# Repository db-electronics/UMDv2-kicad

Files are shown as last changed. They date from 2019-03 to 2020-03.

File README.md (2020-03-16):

# UMDv2
The Universal Mega Dumper v2 project aims to be a complete open-sourced solution for cartridge dumping and writing. It includes a very performant MCU which has a direct memory connection to a generalized databus consisting of 24 address bits and 16 data lines. Along with a dozen or so control signals, it should be sufficient to interface with most cartridge types.

## Cartridge Adapters
The UMDv2 by itself only includes a generalized connector with all its interfacing signals. Cartridge adapters must be used in order to interface to the physical media. All cartridge adapters, as they are created, are added to this project as submodules and will be linked in the CartAdapters directory.

### Cartridge Adapter ID
Each cartridge adapter has an MCP23008 on the I2C bus which identifies the console type for the adapter and thus prevents contention on IO.

* 0x00: no adapter
* 0x01: Sega Genesis 
* 0x02: Sega Master System

# Dependencies
## Parts Libraries
All components in this project depend on my KiCad libraries which are available at https://github.com/db-electronics/kicadlib . I don't use any pre-existing libraries - fight me.

## Firmware
There are two firmware components associated with this PCB: the STM32 fimware and the PC-side client. Both are available here:

* https://github.com/db-electronics/UMDv2-stm32
* https://github.com/db-electronics/UMDv2-python

Please note that version 2.0 is in its absolute infancy, don't expect to find any working releases in the firmware links above for the time being. The links are for provided provideness for completeness of documentation.

# Releases
## 2.0
https://oshpark.com/shared_projects/2dKXBoCG

The PCB version 2.0 release files are available in the releases section https://github.com/db-electronics/UMDv2-kicad/releases. Please note that this PCB is as of yet untested. Build at your own risk. I will post updates when I have begun testing this latest release.

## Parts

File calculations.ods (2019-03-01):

SET DESIRED VALUES
R3 | 43200 | ohms
ENUV | 4.6 | volts
OVP | 5.4 | volts
ILIM | 0.45 | amps
EXACT VALUES
R(ilim) | 43616 | ohms
R1 + R2 | 124627 | ohms
R2 | 7513 | ohms
R1 | 117114 | ohms
NEAREST 1% VALUES
R(ilim) | 43200 | ohms
R1 | 118000 | ohms
R2 | 7500 | ohms
R3 | 43200 | ohms
RECALCULATED WITH 1%
ENUV | 4.625 | volts
OVP | 5.428 | volts
I Limit | 0.446 | amps

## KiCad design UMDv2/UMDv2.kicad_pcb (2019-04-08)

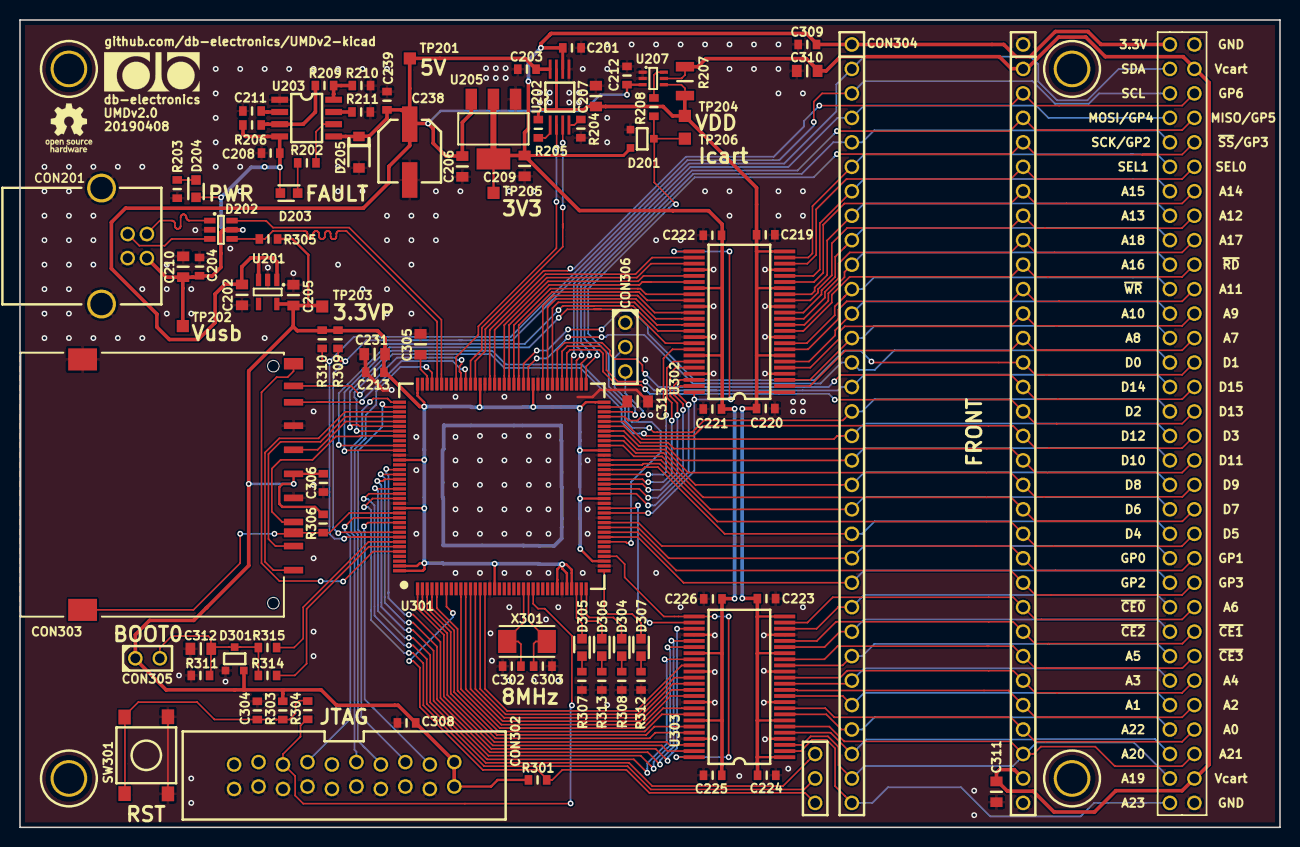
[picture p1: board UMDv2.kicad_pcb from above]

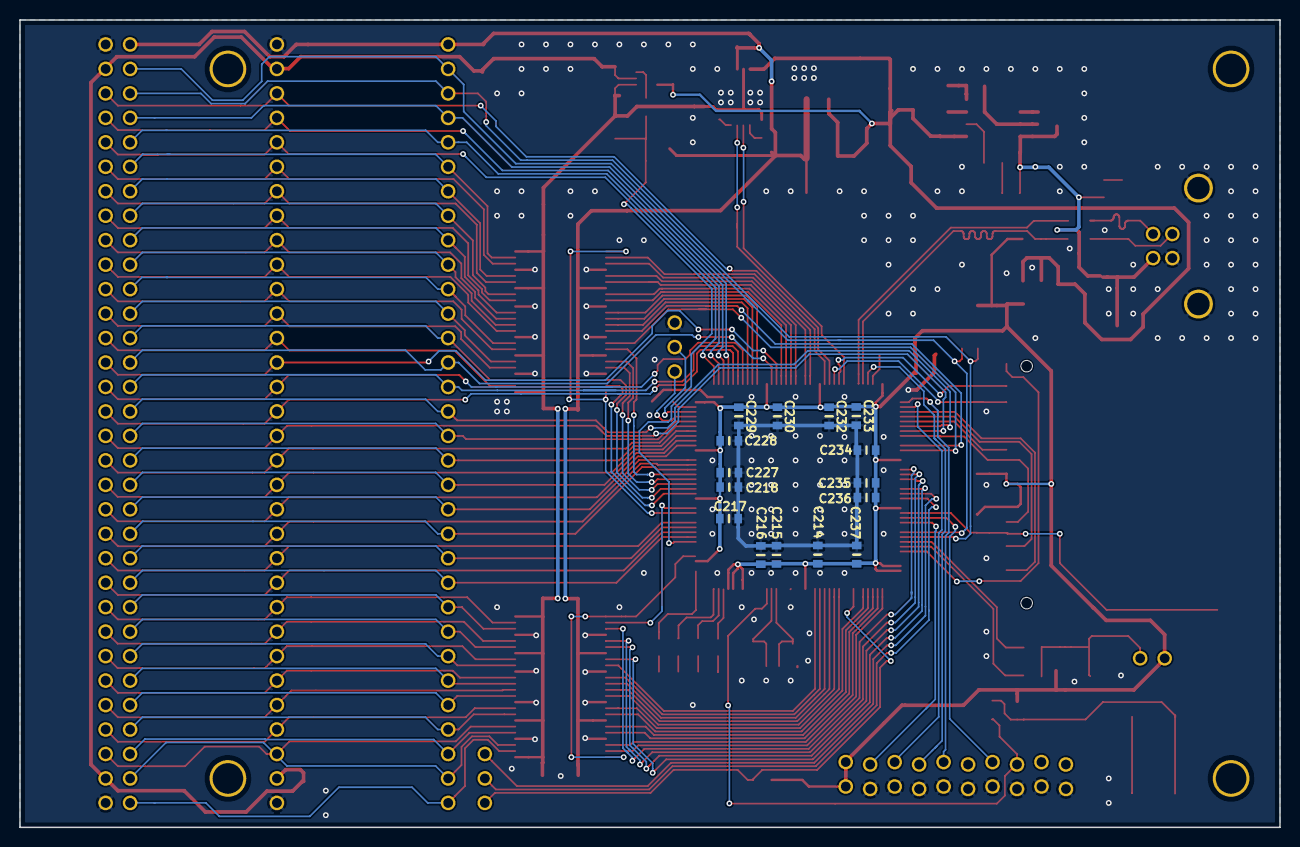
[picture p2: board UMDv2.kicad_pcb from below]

Board: 2 copper layers, 130.8 x 83.8 mm, 112 parts (15 on the bottom side), 152 nets.

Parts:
C201, C203, C204, C208, C212, C213, C214, C215, C216, C217, C218, C219, C220, C221, C222, C223, C224, C225, C226, C227, C228, C229, C230, C232, C233, C234, C235, C236, C237, C239, C304, C306, C308, C309: 0.1uF/50V; 0603
C202, C205, C206, C207, C209, C310, C311, C312: 10uF/16V; 0805
C210: 1uF/16V; 0805
C211: 1nF/50V; 0603
C231: 4.7uF/10V; 0805
C238: 22uF/50V; SMD-6.6x6.6
C302, C303: 18pF/10V; 0603
C305, C313: 2.2uF/10V; 0805
CON201: USB-B1HSB6; USB-B1HSxx
CON302: JTAG-2X10-HDR; HDR2X10-JTAG-SHROUD
CON303: 101-00405-75; SDCARD-AMP-10100405
CON304: UMDv2-CONN; UMD-CONN-DIP64-2
CON305: HDR1X2
CON306: HDR1X3
D201, D301: BAT54S; SOT23
D202: USBLC6-2SC6; SOT-23-6
D203, D204: LG_M67K-G1J2-24-Z; SMD-2
D205: BZT52-B5V6J; SOD123
D304, D305, D306, D307: LO_M67K-K2M1-24-Z; SMD-2
MEC101, MEC102, MEC103, MEC104: NSP-4-6-01; 4-40-SCREW
R202, R203, R307, R308, R312, R313: 750; 0603
R204: 1.20k; 0603
R205, R303, R306: 10.0k; 0603
R206: 118k; 0603
R207: 0.1; 1206
R208: 100; 0603
R209: 7.50k; 0603
R210, R211: 43.2k; 0603
R301, R309, R310: 2.20k; 0603
R304, R314, R315: 470; 0603
R305: 1.50k; 0603
R311: 220k; 0603
SW301: PTS645SM43SMTR92_LFS; PTS645
TP201, TP202, TP203, TP204, TP205, TP206: TP_50; TP50
U201: MIC5504-3.3YM5-TR; SC-74A
U202: TPS2115APWR; TSSOP-8_4.4mm
U203: TPS25921ADR; SOIC-8-3.9MM
U205: AZ1117CH-3.3TRG1; SOT-223
U207: INA199A2DCKR; SOT-363
U301: STM32F413ZHT6; LQFP-144
U302, U303: 74ALVC164245DL,118; BSSOP-48-7.50mm
X301: ECS-80-18-30-JGN-TR; ECX-53
logo101: db Electronics Logo; db-logo_10mm
logo102: OSHW Logo; oshw-logo_5mm

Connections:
+3.3VP: C205.1, C213.2, C214.2, C215.2, C216.2, C217.2, C218.2, C227.2, C228.2, C229.2, C230.2, C231.1, C232.2, C233.2, C234.2, C235.2, C236.2, C237.2, C306.2, C308.2, CON302.1, CON302.2, CON303.4, CON305.1, D301.2, R301.1, R303.2, R305.1, R306.1, R309.1, R310.1, TP203.1, U201.5, U301.17, U301.30, U301.32, U301.33, U301.39, U301.52, U301.62, U301.72, U301.84, U301.95, U301.108, U301.121, U301.131, U301.143, U301.144
+3V3: C201.2, C209.1, C221.2, C222.2, C225.2, C226.2, C309.2, CON304.1, D201.2, TP205.1, U202.6, U205.2, U302.31, U302.42, U303.31, U303.42
+5V: C202.1, C203.2, C206.1, C212.2, C238.1, C239.2, D205.1, TP201.1, U201.1, U201.3, U202.8, U203.5, U205.3, U207.3
/Microcontroller/A0: U301.10, U303.40
/Microcontroller/A1: U301.11, U303.38
/Microcontroller/A2: U301.12, U303.37
/Microcontroller/A3: U301.13, U303.36
/Microcontroller/A4: U301.14, U303.35
/Microcontroller/A5: U301.15, U303.33
/Microcontroller/A6: U301.50, U303.26
/Microcontroller/A7: U301.53, U302.47
/Microcontroller/A8: U301.54, U302.46
/Microcontroller/A9: U301.55, U302.44
/Microcontroller/A10: U301.56, U302.43
/Microcontroller/A11: U301.57, U302.41
/Microcontroller/A12: U301.87, U302.33
/Microcontroller/A13: U301.88, U302.32
/Microcontroller/A14: U301.89, U302.30
/Microcontroller/A15: U301.90, U302.29
/Microcontroller/A16: U301.80, U302.37
/Microcontroller/A17: U301.81, U302.36
/Microcontroller/A18: U301.82, U302.35
/Microcontroller/A19: U301.2, U303.46
/Microcontroller/A20: U301.3, U303.44
/Microcontroller/A21: U301.4, U303.43
/Microcontroller/A22: U301.5, U303.41
/Microcontroller/A23: U301.1, U303.47
/Microcontroller/A24: CON304.65, U301.128
/Microcontroller/A25: CON304.66, U301.129
/Microcontroller/BOOT0: C312.1, CON305.2, D301.3, R311.2, R314.1, R315.2
/Microcontroller/BOOT_EN: R314.2, U301.139
/Microcontroller/D0: CON304.14, U301.85
/Microcontroller/D1: CON304.51, U301.86
/Microcontroller/D2: CON304.16, U301.114
/Microcontroller/D3: CON304.48, U301.115
/Microcontroller/D4: CON304.21, U301.58
/Microcontroller/D5: CON304.44, U301.59
/Microcontroller/D6: CON304.20, U301.60
/Microcontroller/D7: CON304.45, U301.63
/Microcontroller/D8: CON304.19, U301.64
/Microcontroller/D9: CON304.46, U301.65
/Microcontroller/D10: CON304.18, U301.66
/Microcontroller/D11: CON304.47, U301.67
/Microcontroller/D12: CON304.17, U301.68
/Microcontroller/D13: CON304.49, U301.77
/Microcontroller/D14: CON304.15, U301.78
/Microcontroller/D15: CON304.50, U301.79
/Microcontroller/D+: D202.4, R305.2, U301.104
/Microcontroller/D-: D202.6, U301.103
/Microcontroller/GP0: CON304.22, U301.46
/Microcontroller/GP1: CON304.43, U301.47
/Microcontroller/GP2: CON304.23, U301.44
/Microcontroller/GP3: CON304.42, U301.45
/Microcontroller/GP8: CON304.62, U301.96
/Microcontroller/Icart: D201.3, R208.2, TP206.1, U301.43
/Microcontroller/JRST: CON302.3, U301.134
/Microcontroller/JTCK: CON302.9, U301.109
/Microcontroller/JTDI: CON302.5, U301.110
/Microcontroller/JTDO: CON302.13, U301.133
/Microcontroller/JTMS: CON302.7, U301.105
/Microcontroller/LED0: D307.2, U301.37
/Microcontroller/LED1: D304.2, U301.36
/Microcontroller/LED2: D306.2, U301.35
/Microcontroller/LED3: D305.2, U301.34
/Microcontroller/SCL1: CON304.2, R309.2, U301.136
/Microcontroller/SDA1: CON304.3, R310.2, U301.137
/Microcontroller/SDIO_CK: CON303.5, U301.113
/Microcontroller/SDIO_CMD: CON303.2, U301.116
/Microcontroller/SDIO_D0: CON303.7, U301.98
/Microcontroller/SDIO_D1: CON303.8, U301.99
/Microcontroller/SDIO_D2: CON303.9, U301.111
/Microcontroller/SDIO_D3: CON303.1, U301.112
/Microcontroller/SEL0: U301.92, U302.27
/Microcontroller/SEL1: U301.93, U302.26
/Microcontroller/SPI2_MISO: CON304.61, U301.75
/Microcontroller/SPI2_MOSI: CON304.4, U301.76
/Microcontroller/SPI2_NSS: CON304.60, U301.73
/Microcontroller/SPI2_SCK: CON304.5, U301.74
/Microcontroller/UA0: CON304.36, U303.9
/Microcontroller/UA1: CON304.28, U303.11
/Microcontroller/UA2: CON304.37, U303.12
/Microcontroller/UA3: CON304.27, U303.13
/Microcontroller/UA4: CON304.38, U303.14
/Microcontroller/UA5: CON304.26, U303.16
/Microcontroller/UA6: CON304.41, U303.23
/Microcontroller/UA7: CON304.52, U302.2
/Microcontroller/UA8: CON304.13, U302.3
/Microcontroller/UA9: CON304.53, U302.5
/Microcontroller/UA10: CON304.12, U302.6
/Microcontroller/UA11: CON304.54, U302.8
/Microcontroller/UA12: CON304.57, U302.16
/Microcontroller/UA13: CON304.8, U302.17
/Microcontroller/UA14: CON304.58, U302.19
/Microcontroller/UA15: CON304.7, U302.20
/Microcontroller/UA16: CON304.10, U302.12
/Microcontroller/UA17: CON304.56, U302.13
/Microcontroller/UA18: CON304.9, U302.14
/Microcontroller/UA19: CON304.31, U303.3
/Microcontroller/UA20: CON304.30, U303.5
/Microcontroller/UA21: CON304.35, U303.6
/Microcontroller/UA22: CON304.29, U303.8
/Microcontroller/UA23: CON304.32, U303.2
/Microcontroller/USART3_RX: CON306.2, U301.70
/Microcontroller/USART3_TX: CON306.3, U301.69
/Microcontroller/USEL0: CON304.59, U302.22
/Microcontroller/USEL1: CON304.6, U302.23
/Microcontroller/VSEL0: U202.2, U301.100
/Microcontroller/VSEL1: U202.3, U301.97
/Microcontroller/~CE0~: U301.123, U303.27
/Microcontroller/~CE1~: U301.124, U303.29
/Microcontroller/~CE2~: U301.125, U303.30
/Microcontroller/~CE3~: U301.127, U303.32
/Microcontroller/~DTCT~: CON304.67, R301.2, U301.7
/Microcontroller/~OUT_EN0~: U301.40, U303.25, U303.48
/Microcontroller/~OUT_EN1~: U301.49, U302.25, U302.48
/Microcontroller/~RD~: U301.118, U302.38
/Microcontroller/~RST: CON302.15, R304.1, U301.25
/Microcontroller/~SDCD~: CON303.10, R306.2, U301.132
/Microcontroller/~SDWP~: CON303.11, U301.140
/Microcontroller/~UCE0~: CON304.24, U303.22
/Microcontroller/~UCE1~: CON304.40, U303.20
/Microcontroller/~UCE2~: CON304.25, U303.19
/Microcontroller/~UCE3~: CON304.39, U303.17
/Microcontroller/~URD~: CON304.55, U302.11
/Microcontroller/~UWR~: CON304.11, U302.9
/Microcontroller/~WR~: U301.119, U302.40
/Power Section/Din+: CON201.3, D202.3
/Power Section/Din-: CON201.2, D202.1
GND: C201.1, C202.2, C203.1, C204.2, C205.2, C206.2, C207.2, C208.1, C209.2, C210.2, C211.1, C212.1, C213.1, C214.1, C215.1, C216.1, C217.1, C218.1, C219.1, C220.1, C221.1, C222.1, C223.1, C224.1, C225.1, C226.1, C227.1, C228.1, C229.1, C230.1, C231.2, C232.1, C233.1, C234.1, C235.1, C236.1, C237.1, C238.2, C239.1, C302.2, C303.2, C304.2, C305.2, C306.1, C308.1, C309.1, C310.1, C311.2, C312.2, C313.2, CON201.4, CON201.5, CON302.4, CON302.6, CON302.8, CON302.10, CON302.12, CON302.14, CON302.16, CON302.18, CON302.20, CON303.3, CON303.6, CON303.12, CON304.33, CON304.64, CON306.1, D201.1, D202.2, D205.2, D301.1, R203.2, R204.1, R210.1, R211.1, R307.1, R308.1, R311.1, R312.1, R313.1, SW301.3, SW301.4, U201.2, U202.5, U203.1, U205.1, U207.1, U207.2, U301.16, U301.31, U301.38, U301.48, U301.51, U301.61, U301.83, U301.94, U301.107, U301.120, U301.130, U302.4, U302.10, U302.15, U302.21, U302.28, U302.34, U302.39, U302.45, U303.4, U303.10, U303.15, U303.21, U303.28, U303.34, U303.39, U303.45
unnamed: C211.2, U203.2
unnamed: C302.1, U301.23, X301.2
unnamed: C303.1, U301.24, X301.1
unnamed: C304.1, R303.1, R304.2, SW301.1, SW301.2
unnamed: C305.1, U301.106
unnamed: C313.1, U301.71
unnamed: D203.1, R202.2
unnamed: D204.1, R203.1
unnamed: D304.1, R308.2
unnamed: D305.1, R307.2
unnamed: D306.1, R313.2
unnamed: D307.1, R312.2
unnamed: R202.1, U203.6
unnamed: R204.2, U202.4
unnamed: R205.1, U202.1
unnamed: R206.2, R209.1, U203.3
unnamed: R208.1, U207.6
unnamed: R209.2, R210.2, U203.8
unnamed: R211.2, U203.7
unnamed: R315.1, U301.138
VDD: C207.1, C219.2, C220.2, C223.2, C224.2, R205.2, R207.2, TP204.1, U202.7, U207.4, U302.1, U302.7, U302.18, U302.24, U303.1, U303.7, U303.18, U303.24
Vcart: C310.2, C311.1, CON304.34, CON304.63, R207.1, U207.5
Vusb: C204.1, C208.2, C210.1, CON201.1, D202.5, D203.2, D204.2, R206.1, TP202.1, U203.4

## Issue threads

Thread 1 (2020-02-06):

SD card footprint ground tabs are in wrong position

db-electronics, 2020-02-06:
All of the important electrical connection are solderable, but the two tabs near the front (card input side) of the footprint are not correct.

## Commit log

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2018-09-08 added SD card connector
    [UMDv2.sch]
2018-09-09 working on schematic, added some parts to PCB
    [UMDv2.kicad_pcb, UMDv2.sch]
2018-09-09 added USB ESD diode
    [UMDv2.sch]
2018-09-09 working on schematic, how many commit msgs can I come up with?
    [UMDv2.kicad_pcb, UMDv2.sch]
2018-09-10 alternate USB power input
    [UMDv2.kicad_pcb, UMDv2.sch]
2018-09-10 changed load switches because Ste is always right
    [UMDv2.sch]
2018-09-11 added current sense amp
    [UMDv2.kicad_pcb, UMDv2.sch]
2018-09-11 new schematic sheet for power section
    [power.sch]
2018-09-12 added microcontroller sheet to schematic
    [microcontroller.sch, power.sch]
2018-09-13 added component for sense resistor
    [UMDv2.sch, microcontroller.sch, power.sch]
2018-09-14 consistent global pins throughout
    [UMDv2.sch, microcontroller.sch, power.sch]
2018-09-16 added reset circuitry
    [UMDv2.sch, microcontroller.sch, power.sch]
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2018-09-18 re-annotated schematic with new sheet numbers, placed all current components on PCB
    [UMDv2.kicad_pcb, microcontroller.sch, power.sch]
2018-09-18 added first board outline
    [UMDv2.kicad_pcb, UMDv2.sch, microcontroller.sch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]
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2018-09-21 added 4x20 LCD symbol to schematic
    [UMDv2.kicad_pcb, UMDv2.sch, microcontroller.sch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]
2018-10-11 added new hierarchical sheet for user interface
    [UMDv2.sch, microcontroller.sch, power.sch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]
2018-10-16 migrated to KiCad v5
    [UMDv2.sch, microcontroller.sch, power.sch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]
2018-11-06 component placement, bypass caps
    [UMDv2.kicad_pcb, UMDv2.sch, microcontroller.sch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]
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2018-11-07 lots of parts placement
    [UMDv2.kicad_pcb, microcontroller.sch, power.sch]
2018-11-08 routing the power supply section
    [UMDv2.kicad_pcb, UMDv2.sch, microcontroller.sch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]
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2018-11-09 playing with diff routing on USB
    [UMDv2.kicad_pcb, microcontroller.sch]
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2018-11-12 1-2-1-2 patate poil maudit cave mian nana nana
    [UMDv2.kicad_pcb]
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2019-01-09 switched to STM32F407 mcu
    [microcontroller.sch]
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2019-01-11 modifying the sch for STM32F407
    [UMDv2.kicad_pcb, microcontroller.sch, power.sch]
2019-01-14 new pinout on UMDv2 conn
    [UMDv2.kicad_pcb, microcontroller.sch, power.sch]
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2019-01-15 these git commit messages suck, I'm sorry
    [UMDv2.kicad_pcb, microcontroller.sch, power.sch]
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2019-01-17 routing power beneath MCU
    [UMDv2.kicad_pcb]
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2019-01-22 lots of routing work
    [UMDv2.kicad_pcb, microcontroller.sch]
2019-01-24 the time they are a-routing
    [UMDv2.kicad_pcb, microcontroller.sch]
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2019-02-07 added 1.5k pullep to USB D+
    [UMDv2.kicad_pcb, microcontroller.sch]
2019-02-13 changed MCU to STM32F413
    [UMDv2.kicad_pcb, microcontroller.sch]
2019-02-13 fixed pinout issues from MCU change
    [UMDv2.kicad_pcb, microcontroller.sch]
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2019-02-19 removed dual USB, still need an eFUSE
    [UMDv2.kicad_pcb, UMDv2.sch, microcontroller.sch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]
2019-02-20 added eFuse to USB input, remove redundant Vdd load switch
    [UMDv2.kicad_pcb, UMDv2.sch, microcontroller.sch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]
2019-02-22 started parts placement with new power section
    [UMDv2.kicad_pcb, microcontroller.sch, power.sch]
2019-02-22 better power supply caps
    [UMDv2.kicad_pcb, power.sch]
2019-02-22 added note about capacitor on Boot0
    [microcontroller.sch]
2019-02-25 added software control of Boot0 in schematic
    [UMDv2.kicad_pcb, microcontroller.sch, power.sch]
2019-02-27 changed signal names to VSEL0/1, added schottky diode to BOOT0 circuit
    [UMDv2.sch, microcontroller.sch, power.sch]
2019-02-28 power supply placement and routing
    [UMDv2.kicad_pcb, UMDv2.sch, microcontroller.sch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]
2019-03-01 removed QSPI flash and USR_BTN because they won't be necessary
    [UMDv2.kicad_pcb, UMDv2.sch, microcontroller.sch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]
2019-03-01 added calculations spreadsheet for efuse
    [calculations.ods]
2019-03-02 improved USB and power routing, added 2 more user LEDs
    [UMDv2.kicad_pcb, microcontroller.sch, power.sch]
2019-03-02 added new UMD-CONN with testpoints and 4-40 screws
    [UMDv2.kicad_pcb, UMDv2.sch, microcontroller.sch]
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2019-03-07 minor changes to PCB
    [UMDv2.kicad_pcb]
2019-03-13 finished LA connector, started review
    [UMDv2.kicad_pcb, UMDv2.sch, microcontroller.sch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]
2019-03-14 added adapter-genesis project files
    [adapter-genesis.kicad_pcb, adapter-genesis.sch]
2019-03-14 working on GND planes
    [UMDv2.kicad_pcb]
2019-03-14 better organization for cart adapters
    [genesis-umd.kicad_pcb, genesis-umd.sch]
2019-03-15 working on Genesis cart adapter sch
    [genesis-umd.sch]
2019-03-24 connected all signals for genesis adpater
    [genesis-umd.kicad_pcb, genesis-umd.sch]
2019-03-25 not sure what I changed
    [microcontroller.sch]
2019-03-29 updated UMDv2 symbol and footprint, changed AN0-AN1 to A24, A25
    [UMDv2.kicad_pcb, UMDv2.sch, microcontroller.sch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]
2019-04-01 optimizing signals, re-arranged A24/A25 and several GPx on UMDv2 connector
    [UMDv2.kicad_pcb, microcontroller.sch]
2019-04-01 genesis cart adapter work
    [UMDv2.kicad_pcb, genesis-umd.kicad_pcb, genesis-umd.sch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]
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2020-02-10 added 0 jumpers for nWR pin selection to support legacy Bitmap Bureau PCBs
    [genesis-umd.kicad_pcb, genesis-umd.sch]
2020-02-11 moved Genesis adpater to its own repo as a submodule of main UMDv2 project
    [genesis-umd.kicad_pcb, genesis-umd.sch]
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

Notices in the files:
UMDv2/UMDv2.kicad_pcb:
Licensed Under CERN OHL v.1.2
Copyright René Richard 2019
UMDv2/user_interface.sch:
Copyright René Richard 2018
